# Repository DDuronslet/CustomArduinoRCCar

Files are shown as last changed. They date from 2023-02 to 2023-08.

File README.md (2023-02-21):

# CustomArduinoRCCar
Custom RC Car built with an arduino, controlled by a PS4 controller.

Transmitter built using an arduino uno, nrf24l01+ with a 3.3 voltage regulator, 9V battery with switch, and 5K potentiometer.
Reciever built with a 16hz arduino pro micro(uploaded as an arduino leonardo eth),  nrf24l01+ with a 3.3 voltage regulator, 9V battery powering the arduino, and a on board Li-ion battery to power the motor driver, dc motor, servo(buck boost set to 5V).

Motor Driver: TB9051FTG Single Brushed DC Motor Driver Carrier https://www.pololu.com/product/2997
The servo and dc motor were already on board the original RC car which the original reciever was removed.

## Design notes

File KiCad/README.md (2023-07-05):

# CustomArduinoRCCar_PCBs
This will be the folder to contain all of my KiCAD pcb designs.

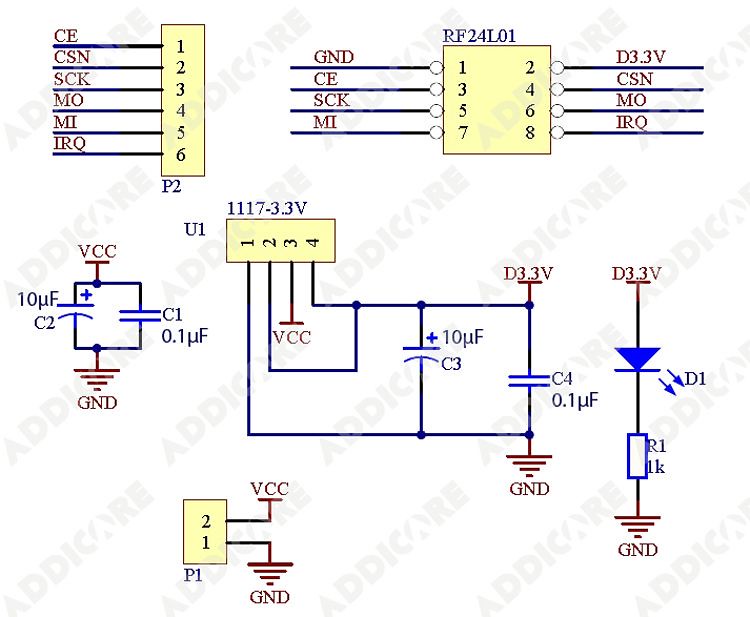
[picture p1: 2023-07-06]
KiCad/DataSheets/Nrf24voltageregulator.jpg

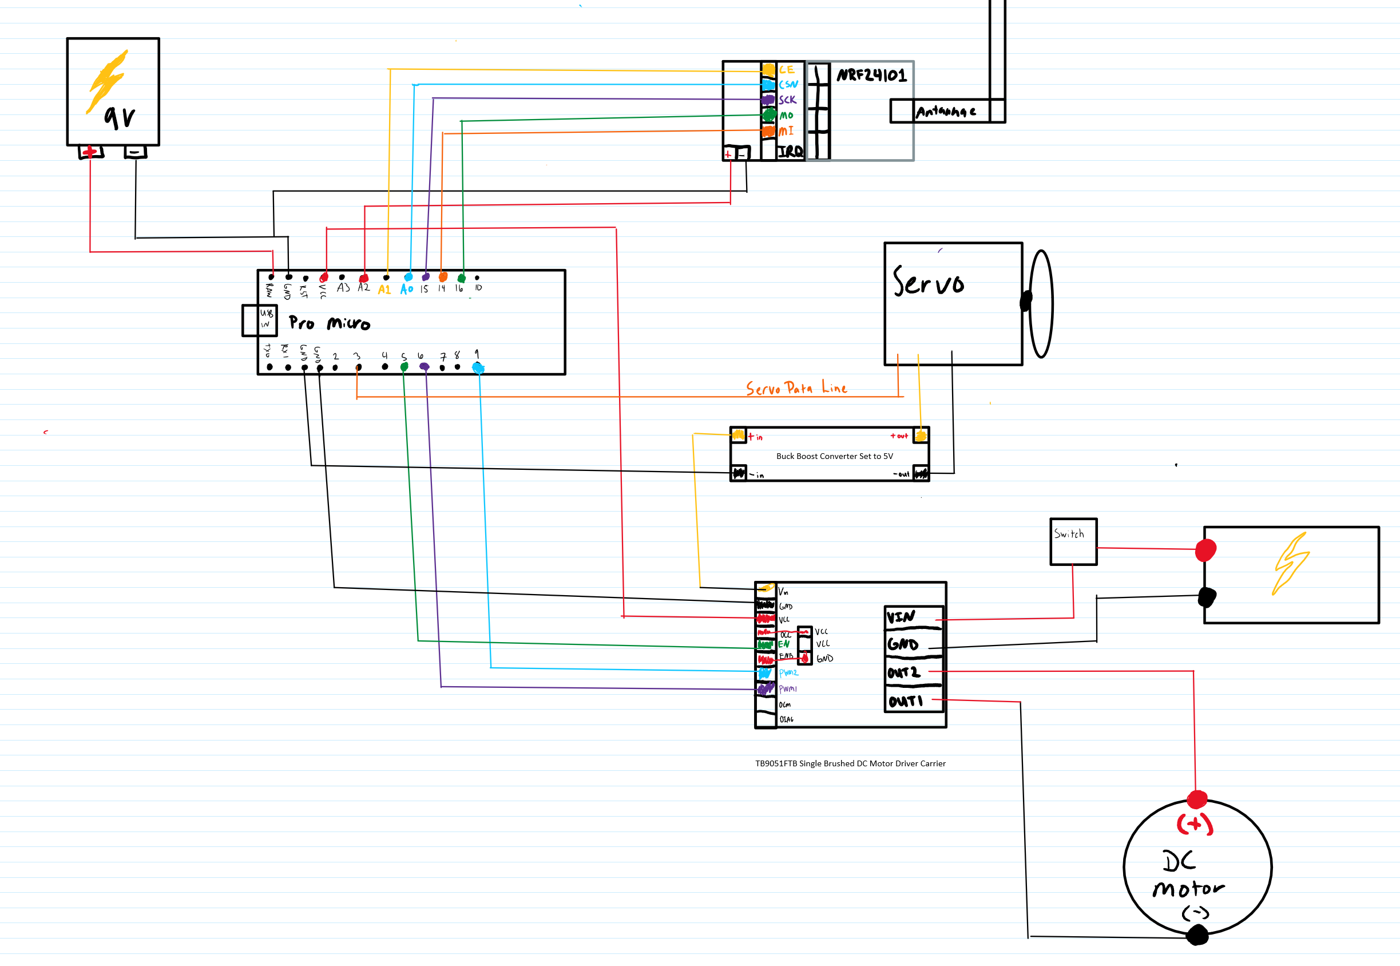
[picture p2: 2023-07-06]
KiCad/Rx/Circuit Drawing/RCcurcuit.png

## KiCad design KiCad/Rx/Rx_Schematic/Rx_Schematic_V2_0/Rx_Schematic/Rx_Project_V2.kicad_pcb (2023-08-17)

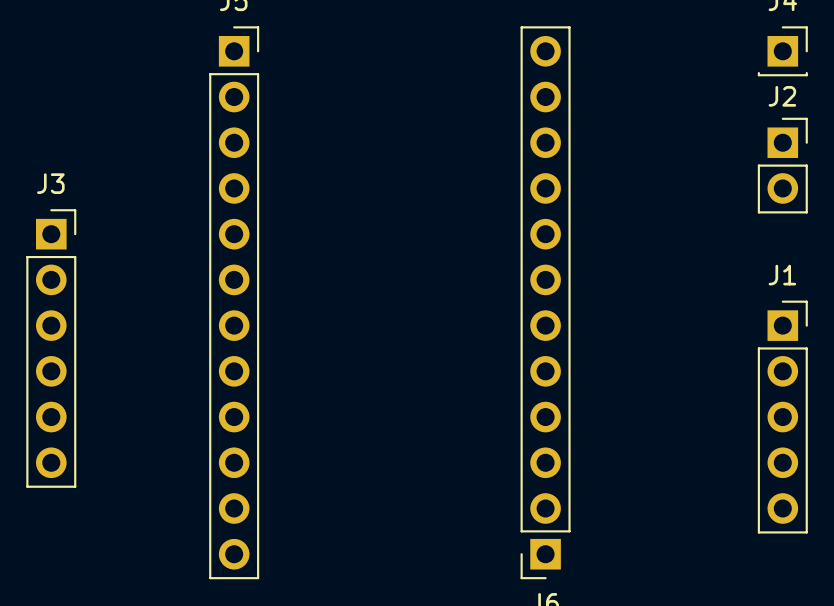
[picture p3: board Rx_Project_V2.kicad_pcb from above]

Board: 2 copper layers, 10 parts (0 on the bottom side), 12 nets, no tracks yet.

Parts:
H1, H2, H3, H4: MountingHole; MountingHole_3.2mm_M3
J1: Conn_01x05; PinSocket_1x05_P2.54mm_Vertical
J2: Conn_01x02; PinSocket_1x02_P2.54mm_Vertical
J3: Conn_01x06; PinSocket_1x06_P2.54mm_Vertical
J4: Conn_01x02; PinSocket_1x01_P2.54mm_Vertical
J5, J6: Conn_01x12; PinSocket_1x12_P2.54mm_Vertical

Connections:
GND: J2.2, J3.1, J5.3, J5.4
unnamed: J1.1, J6.3
unnamed: J1.2, J6.2
unnamed: J1.3, J6.4
unnamed: J1.4, J6.5
unnamed: J1.5, J6.6
unnamed: J2.1, J6.7
unnamed: J3.2, J6.8
unnamed: J3.3, J6.1
unnamed: J3.4, J5.8
unnamed: J3.5, J5.9
unnamed: J3.6, J4.1

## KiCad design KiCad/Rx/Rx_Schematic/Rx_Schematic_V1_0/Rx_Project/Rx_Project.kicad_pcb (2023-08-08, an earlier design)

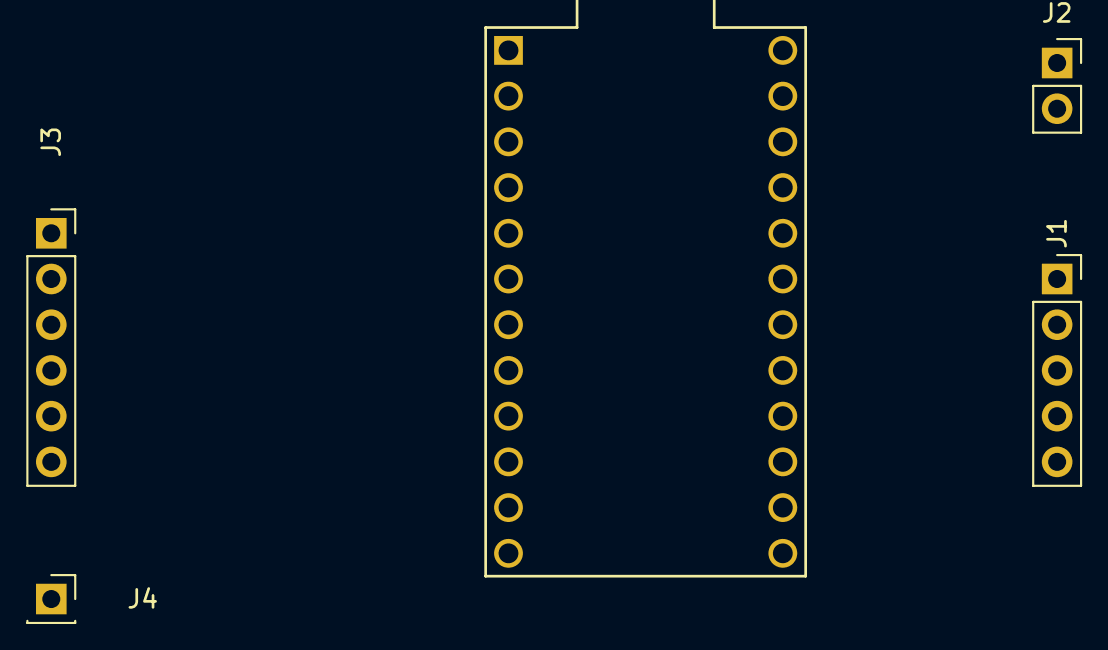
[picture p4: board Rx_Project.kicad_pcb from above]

Board: 2 copper layers, 9 parts (0 on the bottom side), 11 nets, no tracks yet.

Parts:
H1, H2, H3, H4: MountingHole; MountingHole_3.2mm_M3
J1: Conn_01x05; PinSocket_1x05_P2.54mm_Vertical
J2: Conn_01x02; PinSocket_1x02_P2.54mm_Vertical
J3: Conn_01x06; PinSocket_1x06_P2.54mm_Vertical
J4: Conn_01x02; PinSocket_1x01_P2.54mm_Vertical
U1: ProMicro

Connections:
GND: J2.2, J3.1, U1.3 (GND), U1.4 (GND)
unnamed: J1.1, J1.2, U1.14 (B2), U1.15 (B3)
unnamed: J1.3, U1.16 (B1)
unnamed: J1.4, U1.17 (F7)
unnamed: J1.5, U1.18 (F6)
unnamed: J2.1, U1.19 (F5)
unnamed: J3.2, U1.20 (F4)
unnamed: J3.3, U1.13 (B6)
unnamed: J3.4, U1.8 (C6)
unnamed: J3.5, U1.9 (D7)
unnamed: J3.6, J4.1

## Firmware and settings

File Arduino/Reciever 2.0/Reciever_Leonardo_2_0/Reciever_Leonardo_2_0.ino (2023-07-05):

//Ran on a pro micro, but have to upload as a leonardo eth
//nRF24L01+ is used as the radio transmitter, 3.3V breakout adapter helps with noisey 3/5V input
//Arduino powered via a 9V battery w/switch
//Motor driver powered by on board battery nimh?
//Buck boost used to on servo line
 //---( Import needed libraries )---//
#include <SPI.h>
#include <nRF24L01.h>
#include <RF24.h>
#include <Servo.h>

//RF24 definitions
#define SCK_PIN 15
#define MISO_PIN 14
#define MOSI_PIN 16
#define CS_PIN 18
RF24 radio(19, 18); // Create a Radio(CE, CSN)

// TB9051FTGMotorCarrier pin definitions(should all be PWM)
const  uint8_t enPin = 10;
const  uint8_t pwm1Pin = 6;
const  uint8_t pwm2Pin = 5;

//FOR SERVO (Steering)
Servo myservo;
#define servoPin 3 

// NOTE: the "LL" at the end of the constant is "LongLong" type
const uint64_t pipe[1] = { 0xE8E8F0F0E1LL }; // Define the transmit pipe

//---( Declare Variables )---/
int data[9];
int gotArray[9];
int servoAngle = 95;
float SpeedAdjust = 1; 
bool skipCode = false; 
uint16_t counter = 1;
uint16_t prevCounter = 0;

//enum Buttons {
//    Adjust,            // 0
//    LEFT_ANALOG_X = 0, // 1
//    RIGHT_ANALOG_X,    // 2
//    LEFT_ANALOG_Y,     // 3
//    RIGHT_ANALOG_Y,    // 4
//    R2,                // 5
//    L2,                // 6
//    SpeedAdjust,       // 7
//    counter            // 8 
// need 2 more inputs to allow brakemodes?              
//};


void setup()   /**** SETUP: RUNS ONCE ****/
{
//Extra 5V output for Radio Tx
    pinMode(20, OUTPUT);
    digitalWrite(20, HIGH);
    
//Radio Tx Setup  
    Serial.begin(115200);
    delay(100);
    Serial.println("Nrf24L01 Receiver Starting");
    radio.begin();
    radio.setAutoAck(true);
    radio.enableAckPayload();
    radio.enableDynamicPayloads();
    radio.setDataRate(RF24_2MBPS);
    radio.openReadingPipe(1, pipe[0]);
    radio.setRetries(15, 15);
    radio.startListening();
    radio.setPALevel(RF24_PA_MAX); //MAX can also be HIGH and LOW?

//Driver Setup 
  pinMode(enPin, OUTPUT);
  pinMode(pwm1Pin, OUTPUT);
  pinMode(pwm2Pin, OUTPUT);

//Servo Setup
    myservo.attach(servoPin);
    
}
//--(end setup )-

void loop()   /**** LOOP: RUNS CONSTANTLY ****/
{
    if (radio.available()) {
        // Fetch the data payload        
        radio.read(&gotArray, sizeof(gotArray));
    }
    Serial.println("Received array = ");
    for (byte i = 0; i < 9; i++) {
        Serial.println(gotArray[i]);
        data[i] = gotArray[i];
                                    }
//data[8] = counter;
// if (counter == prevCounter) {
//      skipCode = true;
//    }
//    else {
//      skipCode = false;
//    }
//    counter = prevCounter;
//  
//if (!skipCode) {
//Steering Loop
int AnalogStick = map(data[1] , 1, 255, 132 , 54);
    if (data[1] = 0) {
      myservo.write(95 + data[0]);}
    else if ( data[1] < 125) {
      myservo.write(AnalogStick + data[0]); }
    else if ( data[1] > 140) {
      myservo.write(AnalogStick + data[0]); }
//    else {
//      myservo.write(95 + data[0]);
//    }
//130-131 is max left
//52-53 is max right  

//---( Section for DC Motor SpeedAdjust )---//    
    if (data[7] == 4){
      (SpeedAdjust = 1);  
    }
    if (data[7] == 3){
      (SpeedAdjust = 0.75);  
    }
    if (data[7] == 2){
      (SpeedAdjust = 0.5);  
    }
    if (data[7] == 1){
      (SpeedAdjust = 0.35);  
    }
//---( Section for DC Motor Driving )---//  
int Forwards = map(data[5] , 0, 255, 0, 255);
int Reverse = map(data[6] , 0, 255, 0, 255);

int FinalSpeedForwards = (Forwards * SpeedAdjust);
//Boundary Check
 if (FinalSpeedForwards < 0)  {
      FinalSpeedForwards = 0;
    }
 if (Reverse < 0 )  {
      Reverse = 0;
    }   
//Drive Forwards/Backwards
    if (Forwards > 5) {
      digitalWrite(enPin, HIGH);    // Enable
      analogWrite(pwm1Pin, 0 );  // Forward
      analogWrite(pwm2Pin, FinalSpeedForwards);
    }
    else if (Reverse > 5) {
      digitalWrite(enPin, HIGH); //Enable
      analogWrite(pwm1Pin, Reverse);      // Reverse
      analogWrite(pwm2Pin, 0);
    }
    else if (  Forwards < 25  && Reverse < 25 ) {
      digitalWrite(enPin, LOW);     // Enable
      analogWrite(pwm1Pin, 0);      // Coast
      analogWrite(pwm2Pin, 0);
    }
    else if (Forwards > 255 || Reverse > 255) {
      digitalWrite(enPin, HIGH);     // Enable
      analogWrite(pwm1Pin, 0);      // Stop
      analogWrite(pwm2Pin, 0);
    }
}
//} 

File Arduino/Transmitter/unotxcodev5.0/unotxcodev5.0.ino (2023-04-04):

//This code is ran on an arduino uno, with a 5K potentiometer
//nRF24L01+ is used as the radio transmitter, 3.3V breakout adapter helps with noisey 3/5V input
//USB host shield for PS4 controller has the VBUS 5V 2 pins shorted and the 3/5V next to ground shorted to each other respectively
//Transmitter powered via a 9V battery to the DC in with a switch wired in
//-----( Import needed libraries )-----/
#include <PS4USB.h>
#include <SPI.h>
#include <nRF24L01.h>
#include <RF24.h>
USB Usb;
PS4USB PS4(&Usb);

//-----( Declare Constants and Pin Numbers )---/
#define SCK_PIN 13
#define MISO_PIN 12
#define MOSI_PIN 11

#define PS4_VID         0x054C // Sony Corporation
#define PS4_PID         0x05C4 // PS4 Controller
#define PS4_PID_SLIM    0x09CC // PS4 Slim Controller

// NOTE: the "LL" at the end of the constant is "LongLong" type
const uint64_t pipe[1] = {0xE8E8F0F0E1LL}; // Define the transmit pipe

//Potentiometer Stuff To Allow more "On the Fly" Adjustments
int potPin = A5; //Middle pin of Pot to Analog pin A3
int potVal = 0;
int PowerPin1 = 2;//For an extra 5V output for Pot +

//---( Declare objects )---/
RF24 radio(7, 8); // Create a Radio // (CE, CSN)

//---( Declare General Variables )---/
int Array[9]; //Can run into issues sending too many values, confirmed up to 8 works, might be a PC issue with too many com ports being used
int SpeedAdjust = 4; //Variable to adjust top speed
int count = 0; //Count variable to determine if disconnected

void setup()   /**** SETUP: RUNS ONCE ****/
{
  radio.begin();
  radio.setAutoAck(true);
  radio.enableAckPayload();  //If disabled, will get faster receieve/transmission but may have interference  
  radio.enableDynamicPayloads();
  radio.setDataRate(RF24_2MBPS); //CAN MESS WITH THIS
  radio.stopListening();
  radio.openWritingPipe(pipe[0]);
  radio.setRetries(15, 15);
  radio.setPALevel(RF24_PA_HIGH);//Changing HIGH to RF24_PA_MAX
Serial.begin(115200); {
#if !defined(__MIPSEL__)
      while (!Serial); 
#endif
      if (Usb.Init() == -1) {
        Serial.print(F("\r\nOSC did not start"));
        while (1); // Halt
      }
      Serial.print(F("\r\nPS4 USB Library Started"));
   }
   
//Potentiometer Stuff, Need 5V Output to pull from
pinMode(PowerPin1, OUTPUT);
digitalWrite(PowerPin1, HIGH);

}//--(end setup )-


void loop() {
      Usb.Task();
      if (PS4.connected()) 
{ 
  count++; // Increase count by one each loop
if (count == 5000) {
  count = 0; // reset count when it hits 5000
}
  if (PS4.getButtonClick(SQUARE) == 1 ){
      (SpeedAdjust = SpeedAdjust + 1);
  }
  if (PS4.getButtonClick(CIRCLE) == 1 ){
      (SpeedAdjust = SpeedAdjust - 1);
  }
  if (SpeedAdjust < 1) {
    (SpeedAdjust = 1);
  }
  if (SpeedAdjust > 4 ) {
    (SpeedAdjust = 4);
  }
  if (SpeedAdjust >= 4) {
      PS4.setLed(Green);
  }
  if (SpeedAdjust == 3) {
      PS4.setLed(Blue);
  }
  if (SpeedAdjust == 2) {
      PS4.setLed(Yellow);
  }
  if (SpeedAdjust <= 1) {
      PS4.setLed(Red);
  }

   potVal = analogRead(potPin);      
   int adjust = map(potVal, 0, 1000, -45, 45); 
   Array[0] = adjust ; //Potentiometer mapped value
   Array[1] = (PS4.getAnalogHat(LeftHatX));
   Array[2] = (PS4.getAnalogHat(RightHatX));
   Array[3] = (PS4.getAnalogHat(LeftHatY));  
   Array[4] = (PS4.getAnalogHat(RightHatY));  
   Array[5] = (PS4.getAnalogButton(R2));
   Array[6] = (PS4.getAnalogButton(L2));
   Array[7] = (SpeedAdjust);
   Array[8] = count;
//   Array[] = (PS4.getButtonClick(SQUARE));
//   Array[] = (PS4.getButtonClick(CIRCLE));
//   Array[] = (PS4.getAnalogButton(R1));
//   Array[] = (PS4.getAnalogButton(L1));
//   Array[] = (PS4.getButtonClick(CROSS));
//   Array[] = (PS4.getButtonClick(TRIANGLE));
//   Array[] = (PS4.getButtonPress(R3));
//   Array[] = (PS4.getButtonPress(L3));
//   Array[] = (PS4.getButtonPress(LEFT));
//   Array[] = (PS4.getButtonPress(RIGHT));
//   Array[] = (PS4.getButtonPress(UP));
//   Array[] = (PS4.getButtonPress(DOWN));
//   Array[] = (PS4.getButtonPress(TOUCHPAD));
//   Array[] = (PS4.getButtonPress(OPTIONS));
//   Array[] = (PS4.getButtonPress(SHARE));
//   Array[] = (PS4.getButtonPress(PS));


// Can change press to click if i want it to return true only when its initially pressed

//For Tilt Controls
//(PS4.getAngle(Pitch)); 
//(PS4.getAngle(Roll));
   // PS4.setLedFlash(0, 0); // Turn off blinking
   // PS4.setLed(Green/red/blue/yellow);
      //Can maybe do something with later if battery is dying
}
    Serial.println("Sent array = ");
    for (byte i = 0; i < 9; i++) {
        Serial.println(Array[i]);
    }
if (radio.available());
 radio.write(&Array, sizeof(Array));

  }
 
// }
//}

//--(end main loop )-

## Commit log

2023-03-02 Added Serial Print for SpeedAdjust
2023-03-02 Revert "Added Serial Print for SpeedAdjust"
    This reverts commit 4e2cd502759358e1a0d656ba48e68f5262eff252.
    [micro_leonardoethrxcodev5.0.ino]
2023-03-02 Revert "Added SpeedAdjust"
    This reverts commit 5e436f546585fd83684232c679e175a56cd96971.
    [micro_leonardoethrxcodev5.0.ino, unotxcodev5.0.ino]
2023-03-03 Prevented values of 5 and 0 for speed limiter
    [unotxcodev5.0.ino]
2023-03-30 Matched Rx to Tx code
    Updated Rx code to work with current tx code, verified working aside from speed limiter not working as intended
    [micro_leonardoethrxcodev5.0.ino]
2023-03-31 Removing Motor Carrier Library, adding 2nd code
    Rx codde 2.0 to remove motor library and manually address pwm and en pins
2023-03-31 Updated pin layout on rx
    Pin 9 on arduino pro micro not working as pwm as intended, swap pwm to pins 5 and 6 fixed issue
    [Reciever_Leonardo_2_0.ino]
2023-04-04 Added count for disconnection
    Added count on both tx and rx to make sure if connection is lost the rx will stop the motor.
2023-04-04 Complied Rx
    Fixed code to pass compiling
    [Reciever_Leonardo_2_0.ino]
2023-04-04 Updated rx to set servo to default on boot
2023-07-05 Added ReadMe for KiCad designs
2023-07-06 Updated Folder
    [Rx_Schematic_V1_0.kicad_pcb, Rx_Schematic_V1_0.kicad_sch]
2023-07-06 Added data sheets and symbol for motor driver
    [Rx_Schematic_V1_0.kicad_sch]
2023-07-06 Updated schematic
    [Rx_Schematic_V1_0.kicad_sch]
2023-07-06 Updated Rx schematic
    [Rx_Schematic_V1_0.kicad_sch]
2023-07-11 Started new drawing
    [Rx_Schematic_V1_0.kicad_sch]
2023-07-14 ReCreated Rx Project, and reimported libraries
    [Rx_Project.kicad_pcb, Rx_Project.kicad_sch, Rx_Schematic_V1_0.kicad_pcb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]
2023-07-27 Schematic finished
    [Rx_Project.kicad_sch]
2023-08-08 Remade file to remove nano and add connector pins in place
    [Rx_Project.kicad_pcb, Rx_Project_V2.kicad_pcb, Rx_Project_V2.kicad_sch]
2023-08-17 updated page settings
    [Rx_Project_V2.kicad_pcb]
